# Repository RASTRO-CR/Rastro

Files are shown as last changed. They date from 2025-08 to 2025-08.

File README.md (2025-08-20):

# RASTRO: Sistema de Monitoreo Deportivo en Tiempo Real 🛰️

**RASTRO** es un sistema ciberfísico de alto rendimiento diseñado para el seguimiento en vivo de atletas en competencias deportivas como ciclismo, maratones y rallies. Utilizando una combinación de hardware IoT personalizado, comunicación LoRa de largo alcance y análisis predictivo con Modelos de Lenguaje Grandes (LLM), el sistema ofrece una solución robusta y de bajo costo para la gestión y seguridad de eventos.

```mermaid
graph TD
    subgraph Modulo_Corredor_Wearable
        A[GPS] --> C{ESP32-S3}
        B[IMU] --> C
    end

    subgraph Modulo_CC_Gateway
        E[ESP32 Dev Kit] --> F{API Backend}
    end

    subgraph Infraestructura_Central
        F -- HTTP POST --> G[Base de Datos SQLite]
        F -- Llama a API --> H[LLM en la Nube]
        H -- Respuesta --> F
        I[Frontend React] <--> F
    end

    C -- Paquete Binario LoRa --> E

    style A fill:#bbf7d0,stroke:#22c55e
    style B fill:#bbf7d0,stroke:#22c55e
    style H fill:#c4b5fd,stroke:#8b5cf6
    style I fill:#a5f3fc,stroke:#06b6d4
```

## 🎯 Objetivo del Sistema

El objetivo principal de RASTRO es democratizar el acceso a tecnología de seguimiento profesional, permitiendo a organizadores de eventos locales mejorar drásticamente la seguridad de los competidores y la experiencia de los espectadores. El sistema detecta caídas, predice tiempos de llegada y visualiza toda la acción en un dashboard web moderno e interactivo.

## ✨ Características Principales

* **Seguimiento GPS en Tiempo Real:** Visualización de la posición de cada corredor en un mapa interactivo.
* **Comunicación LoRa de Largo Alcance:** Cobertura fiable en terrenos donde la señal celular es inexistente.
* **Detección de Accidentes en el Borde:** El módulo del corredor utiliza un IMU para detectar impactos y enviar alertas de alta prioridad de forma autónoma.
* **Análisis Predictivo con IA:** Integración con un LLM para generar comentarios de carrera, predicciones y análisis de rendimiento en tiempo real.
* **Interfaz Moderna:** Un dashboard web responsivo construido con React y TypeScript para el monitoreo y la gestión de la carrera.
* **Autonomía Energética:** Módulos de hardware diseñados para operar durante horas con baterías LiPo.

## 🛠️ Stack Tecnológico

| Capa | Tecnología | Propósito |
| :--- | :--- | :--- |
| **Módulo Corredor** | ESP32-S3 (LILYGO T-Beam Supreme) | Microcontrolador principal |
| | C++ (Framework Arduino) | Lenguaje del Firmware |
| | TinyGPS++, RadioLib, XPowersLib, U8g2 | Librerías para GPS, LoRa, PMU y Pantalla |
| **Módulo CC** | ESP32 (Dev Kit) + Módulo LoRa | Gateway de Radio y Wi-Fi |
| | C++ (Framework Arduino) | Lenguaje del Firmware |
| | RadioLib, ArduinoJson | Librerías para LoRa y manejo de JSON |
| **Backend** | Python 3.11+ | Lenguaje del Servidor |
| | FastAPI, Uvicorn | Framework para la API RESTful |
| | SQLite | Base de datos ligera |
| **Frontend** | React + TypeScript + Vite | Framework de la Interfaz de Usuario |
| | Leaflet, React-Leaflet | Librería para el Mapa Interactivo |
| | TailwindCSS | Estilizado de la Interfaz |
| | Axios | Cliente HTTP para consumir la API |

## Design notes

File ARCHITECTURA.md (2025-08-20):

# Arquitectura del Sistema RASTRO

## Vista General

RASTRO está diseñado como un sistema distribuido de tres capas principales: los **Módulos Corredor** (nodos en el borde), el **Módulo de Centro de Control (CC)** (el gateway), y la **Interfaz de Usuario** (el dashboard web). La comunicación se realiza de forma inalámbrica a través de LoRa y se procesa en un backend central que se comunica con un LLM en la nube.

### Diagrama de Flujo de Datos

```mermaid
graph TD
    subgraph Modulo_Corredor_Wearable
        A[GPS] --> C{ESP32-S3}
        B[IMU] --> C
    end

    subgraph Modulo_CC_Gateway
        E[ESP32 Dev Kit] --> F{API Backend}
    end

    subgraph Infraestructura_Central
        F -- HTTP POST --> G[Base de Datos SQLite]
        F -- Llama a API --> H[LLM en la Nube]
        H -- Respuesta --> F
        I[Frontend React] <--> F
    end

    C -- Paquete Binario LoRa --> E

    style A fill:#bbf7d0,stroke:#22c55e
    style B fill:#bbf7d0,stroke:#22c55e
    style H fill:#c4b5fd,stroke:#8b5cf6
    style I fill:#a5f3fc,stroke:#06b6d4
```

## Capas del Sistema

### 1. Capa de Percepción (Sensores)
* **GPS (L76K):** Ubicado en el Módulo Corredor, captura coordenadas (latitud, longitud), velocidad, altitud y número de satélites.
* **IMU (QMI8658):** Integrado en el Módulo Corredor, mide la aceleración en 3 ejes para la detección de caídas y el análisis de movimiento.

### 2. Capa de Procesamiento Local (Firmware)
* **Módulo Corredor (C++):** Su firmware está optimizado para la eficiencia energética. Lee los sensores, empaqueta los datos en una `struct` binaria de 28 bytes y los transmite vía LoRa.
* **Módulo CC (C++):** Actúa como un puente de protocolos. Recibe el paquete de bytes de LoRa, lo decodifica, lo reconstruye como un objeto JSON y lo envía a través de Wi-Fi a la API del backend.

### 3. Capa de Comunicación
* **LoRa:** Se utiliza para la comunicación entre el corredor y el CC. Se eligió por su largo alcance y bajo consumo, ideal para exteriores.
    * **Decisión de Diseño:** Se transmiten los datos en formato binario (`struct`) en lugar de texto (JSON) para minimizar el tiempo en el aire, lo que reduce el consumo de batería y la probabilidad de colisiones de paquetes.
* **Wi-Fi / HTTP:** El Módulo CC utiliza Wi-Fi para enviar los datos ya procesados en formato JSON a un endpoint RESTful del backend.

### 4. Capa de Lógica y Visualización
* **Backend (Python/FastAPI):** Recibe los datos, los almacena en una base de datos SQLite y expone varios endpoints para que el frontend los consuma. Orquesta las llamadas al LLM para obtener análisis predictivos.
* **Frontend (React/TypeScript):** Es una Single Page Application (SPA) que consume los datos del backend. Utiliza `axios` para hacer polling a los endpoints y `react-leaflet` para visualizar las posiciones y rutas en un mapa interactivo.

## Posibles Mejoras Futuras
* **A-GPS:** Implementar un sistema de GPS Asistido donde los módulos descarguen datos de efemérides de los satélites vía Wi-Fi antes de la carrera para un posicionamiento inicial casi instantáneo.
* **Fusión de Sensores:** Implementar un Filtro de Kalman en el backend que combine los datos del GPS y del IMU para suavizar la trayectoria del corredor y estimar la posición si la señal GPS se pierde temporalmente.
* **WebSockets:** Reemplazar el polling HTTP con una comunicación por WebSockets para una actualización de datos más eficiente y en tiempo real.

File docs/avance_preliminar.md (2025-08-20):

# Avance Preliminar del Proyecto

## 1. Información del Proyecto
- **Nombre del Proyecto:** RASTRO  
- **Equipo y Roles:** 
  - Fabian: Hardware/Firmware, Frontend  
  - Sauddiel: Hardware/Firmware, Backend  

## 2. Descripción y Justificación
- **Problema que se aborda:**  
  Falta de sistemas asequibles para seguimiento en tiempo real en competencias deportivas locales, con capacidad de detectar accidentes y generar estadísticas predictivas.  
- **Importancia y contexto:**  
  Soluciona limitaciones de cobertura en zonas remotas (sin redes móviles) y reduce costos vs. sistemas profesionales. Combina IoT, LoRa y LLM para seguridad y análisis en vivo.  
- **Usuarios/beneficiarios:**  
  Atletas (seguimiento), organizadores (gestión de eventos), equipos médicos (alertas tempranas).  

## 3. Objetivos del Proyecto
- **Objetivo General:**  
  Desarrollar un sistema de seguimiento deportivo con comunicación LoRa, detección de accidentes, y predicción de métricas usando LLM.  
- **Objetivos Específicos:**  
  1. Transmitir ubicación/velocidad de corredores en tiempo real con módulos ESP32 + GPS + IMU.  
  2. Implementar algoritmo de detección de accidentes usando datos de los sensores.  
  3. Predecir tiempos de llegada y riesgos mediante LLM.  
  4. Visualizar datos en dashboard con React y mapas interactivos.  

## 4. Requisitos Iniciales
- **Lista breve de lo que el sistema debe lograr:**  
  - Capturar en tiempo real la ubicación (latitud y longitud) de cada competidor mediante GPS integrado en los módulos ESP32.  
  - Capturar los datos del componente IMU de cada competidor.
  - Transmitir los datos recopilados (posición, velocidad, aceleración, batería, etc.) a través de LoRa hacia un centro de control.
  - Recibir, decodificar y procesar los paquetes LoRa en el centro de control (ESP32 Gateway / Ideaboard), y reenviarlos como JSON al backend vía WiFi.
  - Crear la conexión con el proveedor de LLM mediante API, y realizar las consultas necesarias.
  - Implementar lógica de detección de eventos relevantes como caídas, frenazos o pérdida de señal GPS.
  - Permitir la visualización en tiempo real del estado y posición de los ciclistas a través de una interfaz web.
  - Garantizar un consumo energético eficiente durante toda la competencia.  

## 5. Diseño Preliminar del Sistema
- **Arquitectura inicial (diagrama):**  
  ```mermaid
   graph LR
    A[Módulo Corredor<br>ESP32 + GPS + LoRa] -->|LoRa - RadioLib| B[Centro de Control<br>IdeaBoard + LoRa]
    B --> |Http Request| C[Backend<br>Python + BD]
    C --> |API| D[LLM]
    C --> |FastAPi| E[Frontend<br>React + Mapas]
  ```
  
- **Componentes previstos:**  
  - Microcontrolador:  
    - Módulo Corredor: LILYGO T-Beam SUPREME (ESP32-S3).  
    - Módulo Centro de Control: IdeaBoard/ESP32 + Waveshare Módulo Core1262 HF LoRa.  
  - Sensores/actuadores:  
    - L76K GPS, LORA SX1262, IMU, antena LoRa 915Mhz.  
  - LLM/API: Together AI (LLama) para predicciones y análisis.  
  - Librerías y herramientas (C/C++):  
    - RadioLib
    - ArduinoJson
    - SPI
    - Wire
    - U8g2lib
    - XPowersLib

## 6. Plan de Trabajo
- **Cronograma preliminar:**  
  | Semana | Hitos |  
  |--------|-------|  
  | 18-25 jul | Definir stack técnico, conectar módulos LoRa. |  
  | 26 jul-1 ago | Lógica de alertas, primeros prompts LLM, GUI básica. |  
  | 2-8 ago | Implementar frontend, ajustar backend. |  
  | 9-15 ago | Pruebas integradas, entrega final (19 ago). |  

- **Riesgos identificados y mitigaciones:**  
  - **Riesgo 1:** Bateria insuficiente para cubrir toda la competencia.

    *Mitigación:* Optimizacion mediante el componente PMU.
  - **Riesgo 2:** Falsos positivos en detección de accidentes.  
    
    *Mitigación:* Calibrar/Mejorar prompts con estructura óptima.  

## 7. Prototipos conceptuales
- **Código mínimo de prueba:**  
  ```python
  from together import Together

    # Crea el cliente con tu API Key directamente
    client = Together(api_key="TuApiKeyAquí")  #Aquí iría la llave de API real

    # Puedes cambiar de modelo según necesidads
    MODEL = "meta-llama/Meta-Llama-3.1-8B-Instruct-Turbo"

    def consultar_llm(prompt):
        try:
            response = client.chat.completions.create(
                model=MODEL,
                messages=[
                    {"role": "system", "content": "Eres un experto en análisis de datos de ciclismo competitivo en tiempo real."},
                    {"role": "user", "content": prompt}
                ]
            )
            return response.choices[0].message.content
        except Exception as e:
            return f"Error en LLM: {e}"

    # Datos simulados
    datos_c1 = [
        {"timestamp": "2024-01-01T10:00:00", "lat": 9.93, "lng": -84.08, "speed": 32.1, "accel_x": 0.05, "accel_y": -0.01, "accel_z": 9.81},
        {"timestamp": "2024-01-01T10:00:10", "lat": 9.931, "lng": -84.081, "speed": 33.2, "accel_x": 0.04, "accel_y": -0.02, "accel_z": 9.80},
        {"timestamp": "2024-01-01T10:00:20", "lat": 9.932, "lng": -84.082, "speed": 31.8, "accel_x": 0.06, "accel_y": -0.01, "accel_z": 9.82}
    ]
    datos_c2 = [
        {"timestamp": "2024-01-01T10:00:00", "lat": 9.93, "lng": -84.08, "speed": 30.1, "accel_x": 0.03, "accel_y": -0.01, "accel_z": 9.75},
        {"timestamp": "2024-01-01T10:00:10", "lat": 9.931, "lng": -84.081, "speed": 29.8, "accel_x": 0.02, "accel_y": -0.01, "accel_z": 9.78},
        {"timestamp": "2024-01-01T10:00:20", "lat": 9.932, "lng": -84.082, "speed": 28.5, "accel_x": 0.01, "accel_y": -0.01, "accel_z": 9.74}
    ]

    # Esquemas
    esquemas = {
        "prediccion": {
            "ciclista_id": str,
            "estado_actual": str,
            "tendencia": str,
            "riesgos_detectados": list,
            "tiempo_estimado_llegada": str,
            "comentario_tecnico": str
        }

        # Aquí van los otros esquemas
    }

    def format_datos_tabla(datos_list):
        tabla = "timestamp,lat,lng,spd,accel_x,accel_y,accel_z\\n"
        for row in datos_list:
            tabla += f"{row['timestamp']},{row['lat']},{row['lng']},{row['speed']},{row['accel_x']},{row['accel_y']},{row['accel_z']}\\n"
        return tabla

    def build_prediccion_prompt(ciclista_id, datos_list):
        datos = format_datos_tabla(datos_list)
        return f"""
    Sos un asistente experto en análisis deportivo en tiempo real para competencias de ciclismo.

    A continuación, se presentan los datos recopilados recientemente del ciclista con ID '{ciclista_id}' en formato CSV:

    {datos}

    📌 Descripción de las columnas:
    - timestamp: marca de tiempo
    - lat, lng: coordenadas GPS
    - speed: velocidad en m/s
    - accel_x, accel_y, accel_z: aceleraciones registradas por el sensor IMU

    📋 Tu tarea:
    1. Analizar los patrones de movimiento del ciclista.
    2. Detectar si hay tendencia a mejorar o decaer.
    3. Estimar el tiempo restante de llegada con base en el ritmo.
    4. Identificar señales de cansancio, fatiga o riesgos.

    ⚠ Instrucciones estrictas:
    - Devuelve ÚNICAMENTE el siguiente JSON. No escribas nada más.
    - No incluyas encabezados, explicaciones ni bloques de código.
    - Empieza la respuesta directamente con una llave de apertura.
    - Asegurate de que sea un JSON válido.

    🔁 Devuelve la salida en el siguiente formato JSON:

    {{
    "ciclista_id": "{ciclista_id}",
    "estado_actual": "descripción breve",
    "tendencia": "ascendente | descendente | estable",
    "riesgos_detectados": ["problema1", "problema2"],
    "tiempo_estimado_llegada": "hh:mm:ss",
    "comentario_tecnico": "análisis profesional en pocas frases"
    }}
    """

    # Función genérica para probar cada prompt
    def probar_prompt(nombre, prompt, esquema):
        print(f"\n--- 🔍 Probando {nombre.upper()} ---")
        print(prompt)
        print("\n🧠 Enviando prompt...")
        respuesta = consultar_llm(prompt)
        print("\n📩 Respuesta cruda del LLM:")
        print(respuesta)

    # Ejecutar pruebas
    probar_prompt("prediccion", build_prediccion_prompt("ciclista_001", datos_c1), esquemas["prediccion"])
  ```

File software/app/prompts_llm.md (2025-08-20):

## Prompt 1: Análisis en Carrera (staff técnico)
Uso: Durante la competencia en intervalos de X km/min.

Actúa como analista técnico de ciclismo competitivo. Analiza los siguientes datos secuenciales de un ciclista para detectar tendencias, riesgos y generar predicciones:

Datos:
KM 1:
1) Velocidad: 35.2 km/h, FC: 152 bpm, Cadencia: 88 rpm
...
KM 3:
5) Velocidad: 33.0 km/h, FC: 167 bpm, Cadencia: 78 rpm

Instrucciones:
1) Indica tendencias en velocidad, FC y cadencia.
2) Señala posibles riesgos de fatiga o sobreesfuerzo.
3) Predice rendimiento para los próximos 5 km.
4) Da recomendaciones técnicas para el equipo de apoyo.

Responde de forma técnica, clara y concisa, en máximo 5 puntos.

## Prompt 2: Refinamiento a formato para Dashboard
Uso: Segunda capa si deseas refinar el resultado anterior.

Toma el siguiente análisis técnico y conviértelo en una lista de máximo 5 puntos, cada punto de máximo 2 líneas, claros y accionables para mostrar en un dashboard técnico de ciclismo.

[Pegue aquí el análisis generado por el primer prompt]

## Prompt 3: Resumen post-competencia (staff y reporte técnico)
Actúa como analista de ciclismo competitivo. Genera un resumen técnico del rendimiento del ciclista con estos datos:

- Velocidad promedio: 34.1 km/h
- FC promedio: 162 bpm
- Cadencia promedio: 83 rpm
- Ritmo en subida: 31.2 km/h
- Ritmo en llano: 35.5 km/h

Incluye:
1) Puntos fuertes.
2) Áreas de mejora.
3) Recomendaciones de entrenamiento específicas.

Usa markdown con secciones: ## Puntos Fuertes, ## Áreas de Mejora, ## Recomendaciones.

## Prompt 4: Comparación entre competidores
Actúa como analista técnico de ciclismo competitivo.

Compara estos dos ciclistas:

Juan:
- Velocidad: 34.5 km/h
- FC: 158 bpm
- Cadencia: 85 rpm

Ana:
- Velocidad: 33.9 km/h
- FC: 164 bpm
- Cadencia: 87 rpm

Analiza quién tiene mayor probabilidad de mantener o mejorar su rendimiento en los próximos 10 km y por qué.

Genera un análisis conciso en formato de tabla comparativa y conclusiones claras.

## Prompt 5: Generador de frases para transmisión en vivo
Genera 3 frases de máximo 2 líneas cada una para narración en vivo durante la competencia, que resuman de forma clara y atractiva el rendimiento del ciclista con estos datos:

- Velocidad promedio: 34.3 km/h
- FC: 161 bpm
- Cadencia: 83 rpm
- Último tramo con incremento de 0.5 km/h

Evita tecnicismos complejos, que sea entendible para el público general.

## Prompt 6: Conversión a JSON (opcional para dashboards)
Convierte este análisis en el siguiente formato JSON para ser interpretado automáticamente por un dashboard técnico:

{
  "tendencias": ["", "", ""],
  "riesgos": ["", ""],
  "predicciones": ["", ""],
  "recomendaciones": ["", ""]
}

[Pegue aquí el análisis generado]

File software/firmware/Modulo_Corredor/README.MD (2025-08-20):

<div align="center" markdown="1">
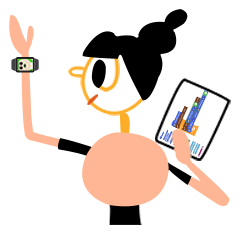
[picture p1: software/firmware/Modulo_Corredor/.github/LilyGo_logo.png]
LilyGo logo
  
</div>

<h1 align = "center">🌟LilyGo LoRa Series🌟</h1>

## News

- Arduino IDE users need to configure the board to be used in the <utilities.h> file in the sketch directory before using the example. The <utilities.h> file contains the pin definitions of the board. If you do not select it, an error will occur during compilation.
- Arduino IDE 用户需要在 Sketch 目录下的 <utilities.h> 文件的最上方配置要使用的开发板，然后才能使用该示例。<utilities.h> 文件包含开发板的引脚定义。如果您未选择该文件，编译时将出现错误。

### `1` Get Started

- 🔧 **[T-Beam Quick Start](./docs/en/t_beam/t_beam_hw.md)**
- 🔧 **[T-Beam Supreme Quick Start](./docs/en/t_beam_supreme/t_beam_supreme_hw.md)**
- 🔧 **[T-Beam BPF Quick Start](./docs/en/t_beam_bpf/t_beam_bpf_hw.md)**
- 🔧 **[T-Beam 2W Quick Start](./docs/en/t_beam_2w/t_beam_2w_hw.md)**
- 🔧 **[LoRa32 V1.3 Quick Start](./docs/en/t3_v13_sx1276/t3_v13_sx1276.md)**
- 🔧 **[LoRa32 V1.6.1 Quick Start](./docs/en/t3_v161_sx1276/t3_v161_sx1276_hw.md)**
- 🔧 **[LoRa32 TCXO Quick Start](./docs/en/t3_tcxo_sx1276/t3_tcxo_sx1276_hw.md)**
- 🔧 **[T3-C6 Quick Start](./docs/en/t3_c6_sx1262/t3_c6_sx1262_hw.md)**
- 🔧 **[T3-S3-SX1262 Quick Start](./docs/en/t3_s3_sx1262/t3_s3_sx1262_hw.md)**
- 🔧 **[T3-S3-LR1121 Quick Start](./docs/en/t3_s3_lr1121/t3_s3_lr1121_hw.md)**
- 🔧 **[T3-S3-SX1280 Quick Start](./docs/en/t3_s3_sx1280/t3_s3_sx1280_hw.md)**
- 🔧 **[T3-S3-SX1280PA Quick Start](./docs/en/t3_s3_sx1280pa/t3_s3_sx1280pa.md)**

## `2` Example description

```bash
./examples/
├── ArduinoLoRa                              # Only support SX1276/SX1278 radio module (仅支持 SX1276/SX1278 无线电模块)
│   ├── LoRaReceiver
│   └── LoRaSender
├── Display                                  # Only supports TBeam TFT Shield
│   ├── Free_Font_Demo
│   ├── TBeam_TFT_Shield
│   ├── TFT_Char_times
│   └── UTFT_demo
├── GPS                                      # T-Beam GPS demo examples
│   ├── TinyGPS_Example
│   ├── TinyGPS_FullExample
│   ├── TinyGPS_KitchenSink
│   ├── UBlox_BasicNMEARead                  # Only support Ublox GNSS Module           
│   ├── UBlox_NMEAParsing                    # Only support Ublox GNSS Module           
│   ├── UBlox_OutputRate                     # Only support Ublox GNSS Module      
│   └── UBlox_Recovery                       # Only support Ublox GNSS Module      
├── LoRaWAN                                  # LoRaWAN examples
│   ├── LMIC_Library_OTTA
│   └── RadioLib_OTAA
├── OLED
│   ├── SH1106FontUsage
│   ├── SH1106GraphicsTest
│   ├── SH1106IconMenu
│   ├── SH1106PrintUTF8
│   ├── SSD1306SimpleDemo
│   └── SSD1306UiDemo
├── PMU                                      # T-Beam & T-Beam S3 PMU demo examples
├── RadioLibExamples                         # RadioLib examples,Support SX1276/78/62/80...
│   ├── Receive_Interrupt
│   └── Transmit_Interrupt
├── Sensor                                   # Sensor examples,only support t-beams3-supreme
│   ├── BME280_AdvancedsettingsExample
│   ├── BME280_TestExample
│   ├── BME280_UnifiedExample
│   ├── PCF8563_AlarmByUnits
│   ├── PCF8563_SimpleTime
│   ├── PCF8563_TimeLib
│   ├── PCF8563_TimeSynchronization
│   ├── QMC6310_CalibrateExample
│   ├── QMC6310_CompassExample
│   ├── QMC6310_GetDataExample
│   ├── QMC6310_GetPolarExample
│   ├── QMI8658_BlockExample
│   ├── QMI8658_GetDataExample
│   ├── QMI8658_InterruptBlockExample
│   ├── QMI8658_InterruptExample
│   ├── QMI8658_LockingMechanismExample
│   ├── QMI8658_MadgwickAHRS
│   ├── QMI8658_PedometerExample
│   ├── QMI8658_ReadFromFifoExample
│   └── QMI8658_WakeOnMotion
|── T3S3Factory                              # T3 S3 factory test examples
└── Factory                                  # T-Beam & T-Beam S3 and BPF factory test examples
```

## `3` Use reference

| Product | Youtube  link | explanation | Status |
| :---: | :---: | :---: | :----: |
| T -BEAM | [Youtube link](https://www.youtube.com/watch?v=Xf1Wf-aTSmc) | How do I drive the T-Beam display  How to use T-Beam for positioning,How to use T-Beams  for communication test | ✅ |
| LilyGo device | [Youtube link](https://www.youtube.com/watch?v=f3BybP3L7ls) | How to enter boot mode to download the firmware | ✅ |

## `4` TTN

To access TTN (The Things Network), please refer to [LilyGo_LoRa_Series_Quick_Start](./docs/zh/LilyGo_LoRa_Series_Quick_Start_On_TTN_zh.md)

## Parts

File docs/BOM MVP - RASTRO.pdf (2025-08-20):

Modelo | Cantidad | Descripcion | Proveedor | Subtotal (Dolares) | Total (Dolares) | Enlace

MODULO CORREDOR - 2x

LILYGO T-BeamSUPREME Meshtastic | 2 | 915Mhz ESP32-S3 LoRa L76K GPS WiFi Bluetooth Módulo TTGO Junta de desarrollo con 1.3 pulgadas SH1106 OLED | Lilygo - AMAZON | $66,00 | $132,00 | https://a.co/d/3sMyP3N
Pack 2 Jesspow Batería recargable 18650 | 1 | 3.7V 3300mAh con Flat-Top Li-ion | JESSPOW BATTERY - AMAZON | $11,99 | $11,99 | https://a.co/d/ecw1ivI
| | | Total Modulo Corredor | $77,99 | $143,99

MODULO CC (Centro de Control) - 1x

CRCibernetica IdeaBoard | | | CRCibernetica | $0,00 | $0,00 | https://www.crcibernetica.com/crcibernetica-ideaboard/?searchid=2434289&search_query=ideaboard
BreadBoard | | | | $0,00 | $0,00
Waveshare Módulo Core1262 HF LoRa | 1 | chip SX1262, dispositivos meshtásticos, comunicación de largo alcance, antiinterferencia, adecuado para banda de sub-GHz | waveshare - AMAZON | $15,99 | $15,99 | https://a.co/d/gXY2bIv
2 unidades de antena LoRa de 915 MHz | 1 | Para interiores 5dBi Gain Omni SMA conector macho para LoRa y Meshtastic + cable de antena IPEX | jiangyuantech - AMAZON | $9,99 | $9,99 | https://a.co/d/6PJZxn3
| | | Total Modulo CC | $25,98 | $25,98
Total BOM | $103,97 | $169,97

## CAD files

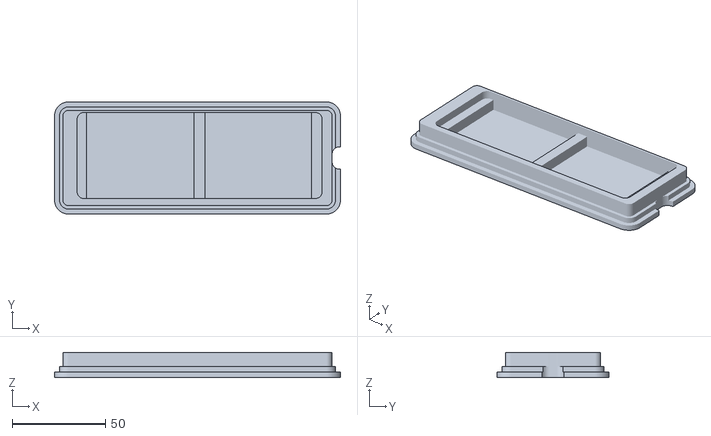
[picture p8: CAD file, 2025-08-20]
docs/Modulo_CC/TAPA ABAJO.stl
153.0 x 60.0 x 13.5

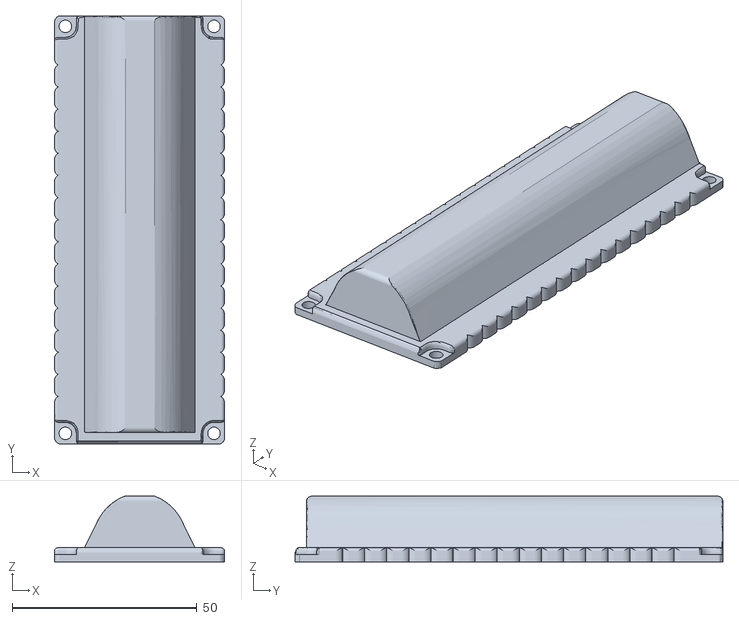
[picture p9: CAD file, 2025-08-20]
docs/Modulo_Corredor/t-beam_supreme_v14_back-18650-flat.stl
46.1 x 115.8 x 17.7

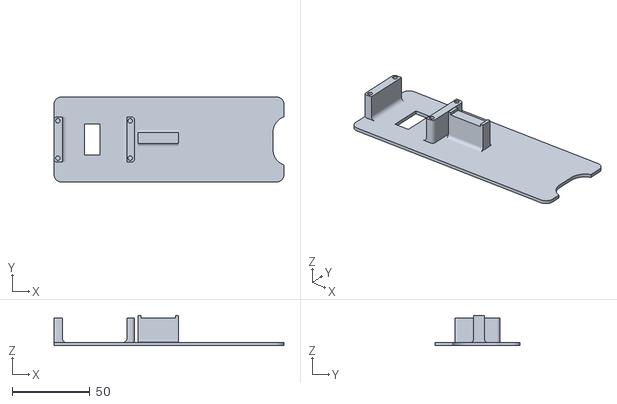
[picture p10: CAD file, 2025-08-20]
docs/Modulo_CC/INTERMEDIO.stl
147.7 x 54.7 x 19.3

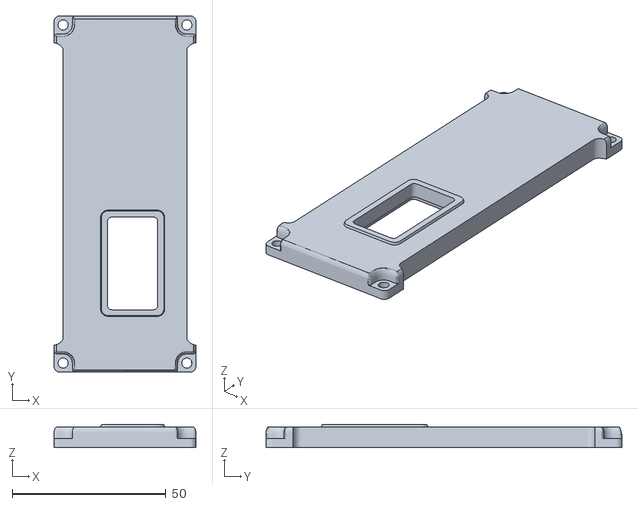
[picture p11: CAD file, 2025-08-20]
docs/Modulo_Corredor/t-beam_supreme_v14_front-blank.stl
46.2 x 115.8 x 7.49

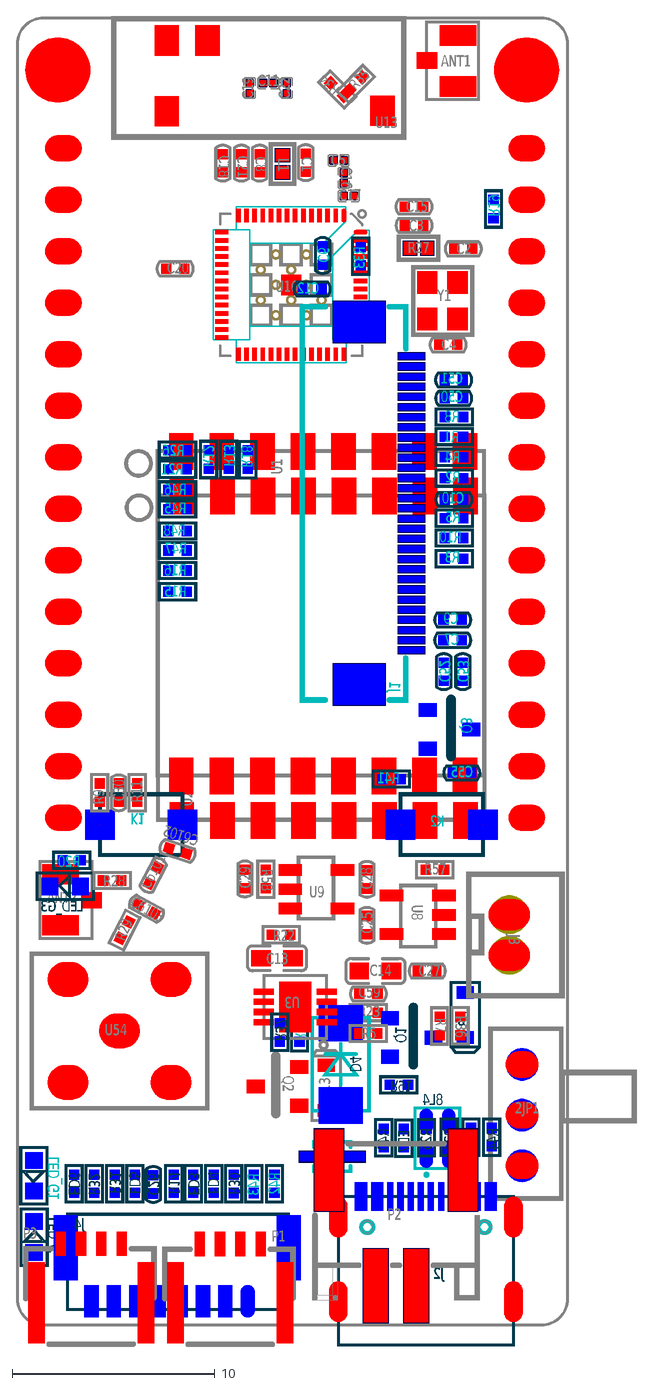
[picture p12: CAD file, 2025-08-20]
software/firmware/Modulo_Corredor/dimensions/T3S3 V1.3.dxf
U16
U54
Y1
C8
C6
R27
C20
ED4
ED6
8L4
U13
ANT1
ANT2
ED3
ED5
ED7
ED8
R19
2JP1
U8
U9
J2
C12
C15
C2
C21
C3
R33
U2
U1
LED_G
LED_G3
D13
Q3
J4
ED1
Q2
P1
P3
K1
C13
C14
C52
C10
C1
C6101
C6102
C6103
C25
C26
C27
C28
C29
C30
C50
C51
C55
R10
R11
R17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

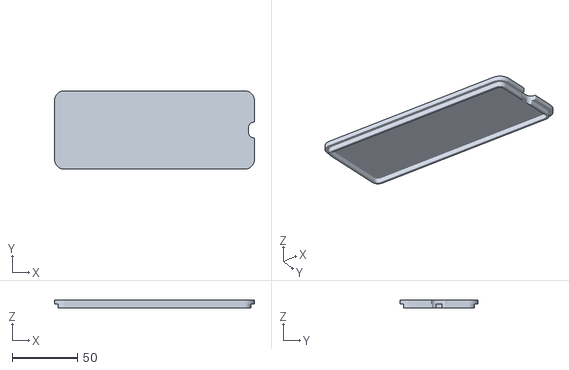
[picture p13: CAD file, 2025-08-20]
docs/Modulo_CC/TAPA ARRIBA.stl
153.0 x 60.0 x 6.00

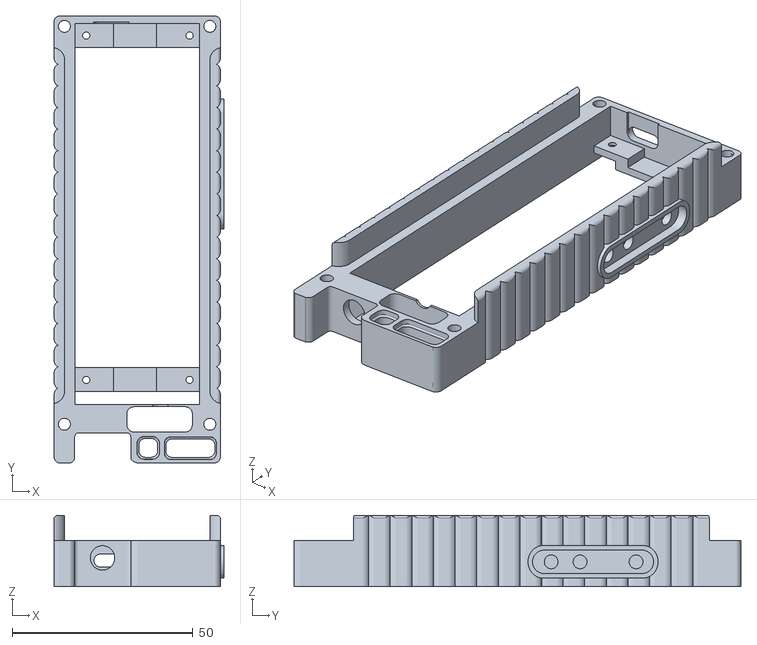
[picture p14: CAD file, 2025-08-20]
docs/Modulo_Corredor/t-beam_supreme_v14a_frame-no-button-cover.stl
47.0 x 123.7 x 19.7

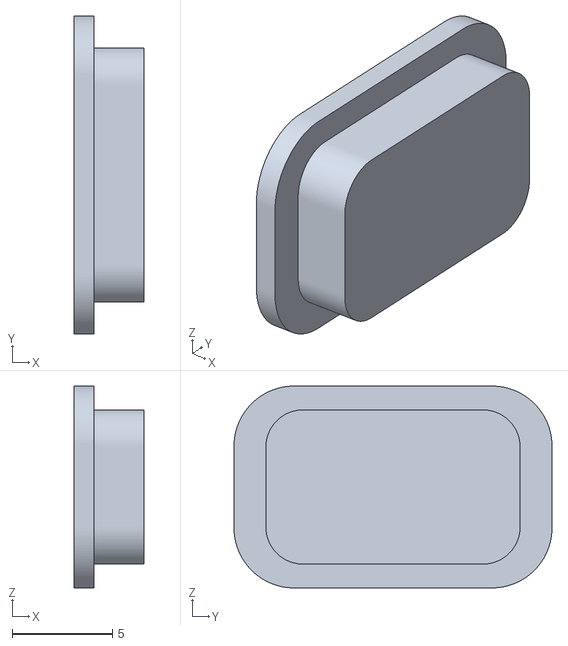
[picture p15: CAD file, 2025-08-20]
docs/Modulo_CC/TAPA POWER.stl
3.50 x 15.9 x 10.1

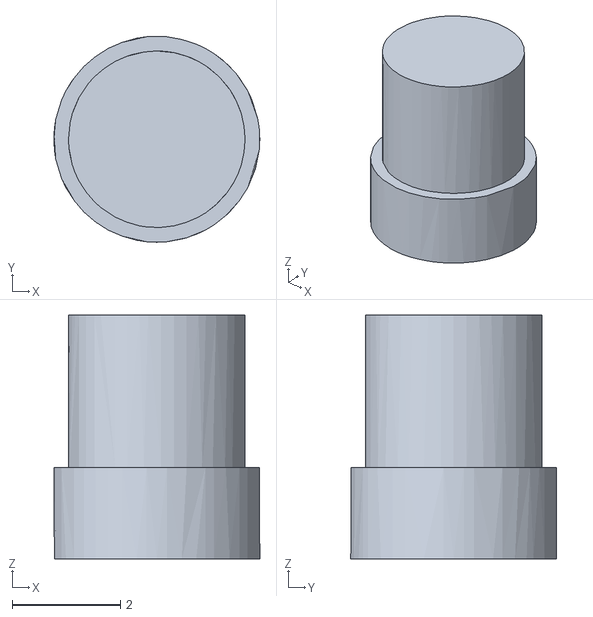
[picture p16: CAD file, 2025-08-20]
docs/Modulo_Corredor/t-beam_supreme_v14_button.stl
3.79 x 3.79 x 4.50

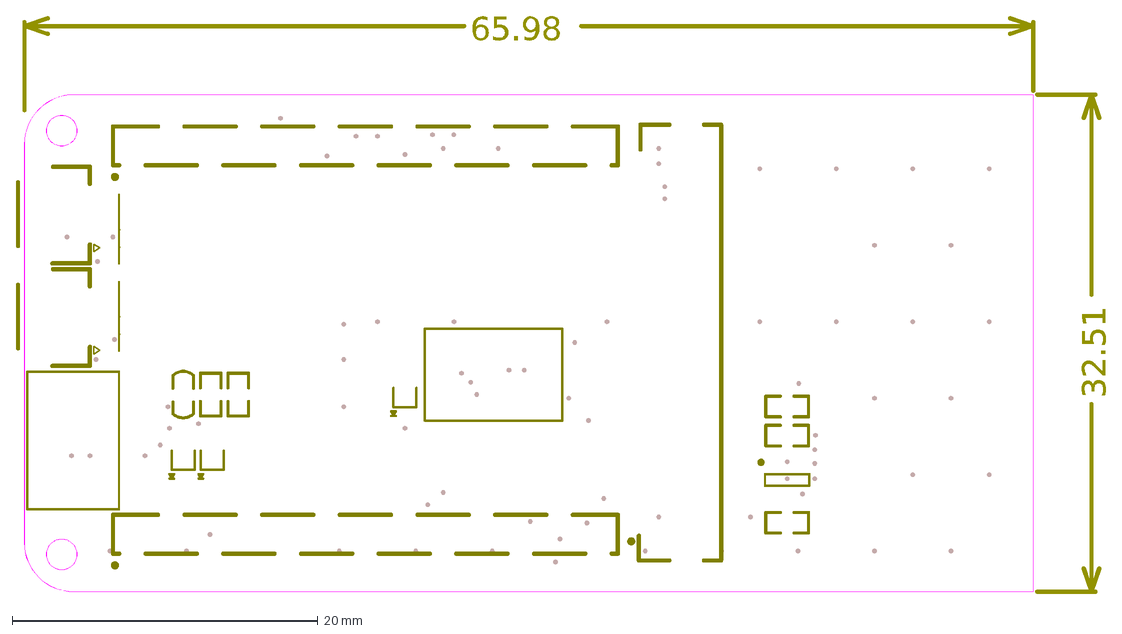
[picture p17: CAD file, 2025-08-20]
software/firmware/Modulo_Corredor/dimensions/T-Beam-Shiled-V1.0.dxf
32.51
65.98

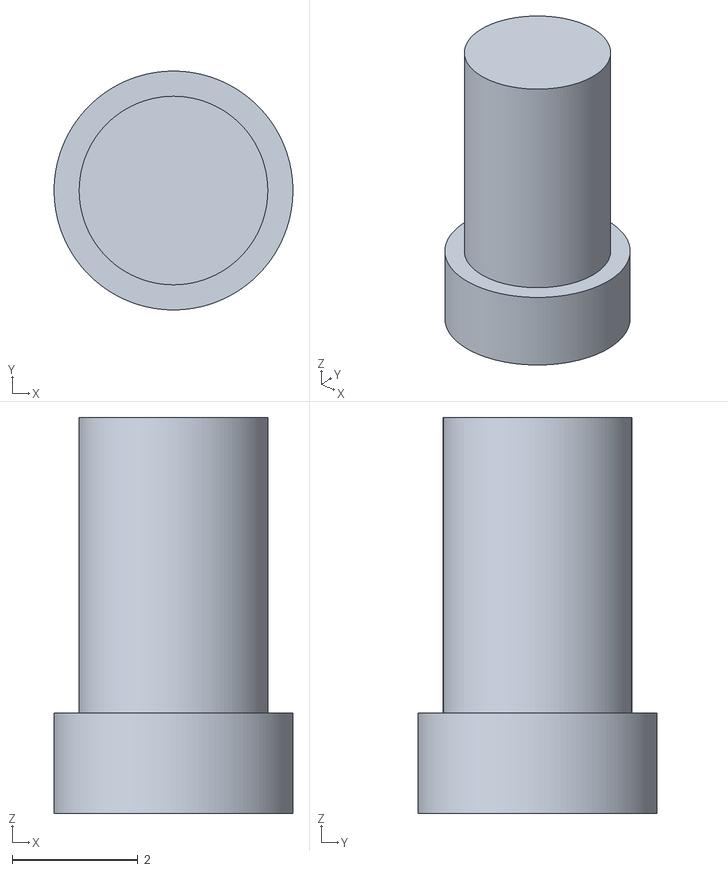
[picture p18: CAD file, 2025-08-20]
docs/Modulo_CC/BOTON.stl
3.80 x 3.80 x 6.30

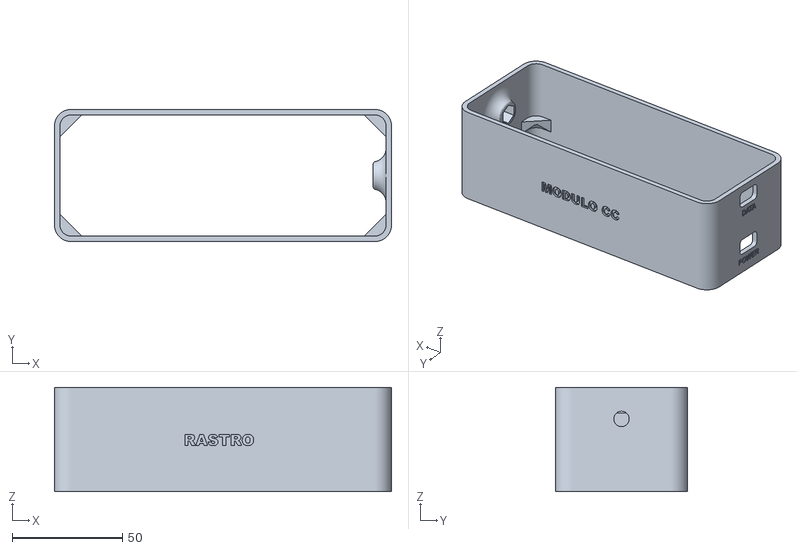
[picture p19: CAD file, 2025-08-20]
docs/Modulo_CC/CUERPO CASE.stl
153.0 x 60.0 x 47.2

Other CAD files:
software/firmware/Modulo_Corredor/dimensions/T3_V1.62.dwg
software/firmware/Modulo_Corredor/dimensions/T3_V1.3.dwg

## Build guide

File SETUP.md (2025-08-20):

# Guía de Instalación y Despliegue de RASTRO

Esta guía te permitirá configurar el entorno completo para el sistema RASTRO, desde el hardware hasta el software.

## 1. Hardware Requerido

### Módulo Corredor
* 1x Placa LILYGO T-Beam S3 Supreme
* 1x Batería LiPo 3.7V con conector JST

### Módulo de Centro de Control (CC)
* 1x Placa de desarrollo ESP32 (ej. ESP32 Dev Kit, CRCibernetica IdeaBoard)
* 1x Módulo LoRa Waveshare Core1262 (SX1262)
* 1x Antena LoRa de 915MHz con cable IPEX a SMA
* 1x Batería LiPo de 3.7V (ej. 5000mAh)
* 1x Módulo de carga LiPo TP4056
* 1x Módulo Boost Converter DC-DC MT3608
* 1x Protoboard y cables Jumper

### Diagrama de Conexiones (Módulo CC)

| Pin en ESP32 (Dev Kit) | Pin en Módulo LoRa (Waveshare) |
| :--- | :--- |
| `3V3` | `3V3` |
| `GND` | `GND` (todos los disponibles) |
| `GPIO18` | `CLK` |
| `GPIO23` | `MOSI` |
| `GPIO19` | `MISO` |
| `GPIO5` | `CS` |
| `GPIO17` | `RESET` |
| `GPIO16` | `BUSY` |
| `GPIO4` | `DIO1` |

## 2. Configuración del Firmware

1.  **Instala VS Code y la extensión PlatformIO IDE.**
2.  **Clona este repositorio:** `git clone https://github.com/your-repo`
3.  **Abre el Proyecto:** En VS Code, usa `File > Open Folder...` y abre la carpeta del repositorio clonado.
4.  **Para el Módulo Corredor:**
    * Abre el archivo `platformio.ini` en la raíz.
    * Asegúrate de que `src_dir` apunte al firmware del corredor (ej. `src_dir = software/firmware/corredor_modulo`).
    * Conecta la placa LILYGO, ponla en modo bootloader si es necesario, y haz clic en el botón "Upload" de PlatformIO.
5.  **Para el Módulo CC:**
    * Abre el archivo `platformio.ini` en la raíz.
    * Cambia `src_dir` para que apunte al firmware del CC (ej. `src_dir = software/firmware/cc_modulo`).
    * Conecta la placa ESP32 Dev Kit, ponla en modo bootloader, y haz clic en "Upload".

## 3. Configuración del Backend

1.  **Navega a la carpeta:** `cd software/backend`
2.  **Crea un entorno virtual:** `python -m venv venv`
3.  **Activa el entorno:**
    * Windows: `.\venv\Scripts\activate`
    * macOS/Linux: `source venv/bin/activate`
4.  **Instala las dependencias:** `pip install -r requirements.txt`
5.  **Ejecuta el servidor:** `python main.py`

## 4. Configuración del Frontend

1.  **Navega a la carpeta:** `cd software/frontend`
2.  **Instala las dependencias:** `npm install`
3.  **Configura la URL de la API:**
    * Crea un archivo llamado `.env` en la carpeta `frontend`.
    * Añade la siguiente línea, reemplazando la IP por la de tu PC donde corre el backend:
        `VITE_API_BASE_URL=http://192.168.100.60:8000`
4.  **Ejecuta la aplicación:** `npm run dev`
5.  Abre la URL que te proporciona la terminal en tu navegador.

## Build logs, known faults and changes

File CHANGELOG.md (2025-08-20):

# Changelog

Todo el historial de cambios notables en el proyecto RASTRO será documentado en este archivo.

El formato está basado en [Keep a Changelog](https://keepachangelog.com/en/1.0.0/), y este proyecto se adhiere a [Semantic Versioning](https://semver.org/spec/v2.0.0.html).

## [1.0.0] - 2025-08-20 (Día de la Expo)

### Added
-   **Documentación Final:** Se completaron y pulieron todos los documentos del repositorio (`README.md`, `ARCHITECTURE.md`, `SETUP.md`) para la evaluación final.
-   **Pruebas de Campo:** Se realizó una prueba de campo final del sistema completo en un entorno exterior, validando la precisión del GPS, la transmisión de datos y la visualización en el dashboard.

### Changed
-   **Versión Estable:** Se marca esta versión como la `1.0.0`, representando el prototipo funcional completo presentado en la ExpoCenfo 2025.

## [0.9.0] - 2025-08-18

### Added
-   **Integración de Actuadores en Módulo CC:** Se implementó el control de un LED RGB y un Buzzer Activo en el Módulo CC para proporcionar feedback visual y sonoro de los estados del sistema (ej. recepción de paquete, alertas).
-   **Gestión de Energía Avanzada:** Se añadió la funcionalidad de "sueño profundo" (deep sleep) al Módulo CC, controlada por un botón externo para un encendido y apagado eficiente.
-   **Diseño de Carcasas (Case):** Se diseñaron e imprimieron en 3D las carcasas finales para el Módulo Corredor y el Módulo CC, cumpliendo con el requisito de fabricación digital.

## [0.8.0] - 2025-08-15 (Entrega Final)

### Added
-   **Frontend Completo:** Se fusionaron las vistas de Administrador y Pública en una sola aplicación con navegación. Se completó el panel de configuración de carrera, incluyendo la carga de archivos GPX.
-   **Backend (Análisis LLM):** Se implementó la lógica para construir prompts dinámicos y realizar llamadas a una API de LLM externa para generar análisis de carrera.
-   **Sistema de Alertas:** Se desarrolló el motor de alertas en el backend para detectar eventos como posibles caídas basadas en los datos del IMU.

## [0.7.0] - 2025-08-12

### Added
-   **Módulo CC (Hardware Oficial):** Se ensambló y validó el Módulo CC final utilizando la placa ESP32 Dev Kit, el módulo LoRa Waveshare y el circuito de alimentación autónomo (Batería LiPo + TP4056 + MT3608).
-   **Firmware Módulo CC (Oficial):** Se adaptó y refinó el firmware del receptor para el nuevo hardware, incluyendo la decodificación de paquetes binarios y la conversión a JSON para su envío al backend.

### Fixed
-   Se resolvieron problemas de `Error -2 (CHIP_NOT_FOUND)` en el Módulo CC oficial a través de un protocolo de diagnóstico de bajo nivel (Escáner SPI) que identificó una conexión física inestable como la causa raíz.

## [0.6.0] - 2025-08-08

### Added
-   **Fusión de Sensores (GPS + IMU):** Se integró exitosamente la lectura de datos del GPS (TinyGPS++) y del IMU (QMI8658) en un único firmware para el Módulo Corredor.
-   **Transmisión de Datos Binarios:** Se definió y se implementó una `struct` de C++ para empaquetar toda la telemetría en un paquete de datos binario y eficiente de 28 bytes.
-   **Visualización Completa en Dispositivo:** La pantalla OLED del Módulo Corredor ahora muestra datos en tiempo real de los satélites GPS y el estado del sistema.

## [0.5.0] - 2025-08-03 (Entrega de Primer Avance)

### Added
-   **Backend Funcional (API):** Se desarrolló la primera versión de la API en Python con FastAPI. Incluye endpoints para recibir datos (`/datos/`) y consultar la última posición (`/datos/{ciclista_id}`).
-   **Frontend (Mapa en Vivo):** Se creó la primera versión de la interfaz de usuario con React y TypeScript, capaz de conectarse a la API y "pintar" la ubicación y el rastro de un corredor en un mapa de Leaflet.

### Fixed
-   **Precisión del GPS:** Se diagnosticó y mitigó el desfase en las coordenadas GPS mediante un protocolo de calibración en un entorno de cielo abierto.
-   **Conectividad Backend-ESP32:** Se resolvieron los errores de conexión (`Error -1`) entre el Módulo CC y el backend, diagnosticando y configurando correctamente el Firewall de Windows.

## [0.4.0] - 2025-07-28

### Added
-   **Arranque de Hardware Estable:** Se logró el arranque consistente de las placas LILYGO T-Beam S3 Supreme después de un proceso de depuración intensivo.
-   **Comunicación LoRa Estable:** Se estableció una comunicación P2P fiable entre dos módulos LILYGO.
-   **Firmware Base:** Se crearon firmwares de transmisión y recepción usando `RadioLib` para validar la capa de radio.

### Changed
-   **Pivote de Estrategia de Desarrollo:** Se adoptó el **repositorio oficial de LilyGo** como entorno de desarrollo base para garantizar la compatibilidad del hardware.

### Fixed
-   **Error Crítico de Arranque:** Se solucionó el fallo que impedía que el firmware se ejecutara en las placas LILYGO al añadir la `build_flag` `-DARDUINO_USB_CDC_ON_BOOT=1` al `platformio.ini`.

## [0.2.0] - 2025-07-24

### Added
-   **Análisis de Arquitectura:** Se diseñó la arquitectura de hardware y software del MVP, incluyendo la selección de componentes y el flujo de datos.
-   **Estructura del Repositorio:** Se creó el repositorio en GitHub con la estructura profesional recomendada (`docs`, `hardware`, `software`, etc.).
-   **Documentación Inicial:** Se crearon los borradores de `README.md` y `ARCHITECTURE.md`.

## [0.1.0] - 2025-07-20

### Added
-   **Concepción del Proyecto:** Se definió la idea, los objetivos y el alcance del proyecto RASTRO.
-   **Análisis de Requisitos:** Se estudió la rúbrica y las reglas de la ExpoCenfo 2025 para alinear el desarrollo del proyecto con los criterios de evaluación.

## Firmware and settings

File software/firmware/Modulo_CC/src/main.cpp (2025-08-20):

/**
 * @file main.cpp
 * @author Fabian Miranda & Sauddiel Montoya
 * @brief Firmware para el Módulo de Centro de Control (CC) del proyecto RASTRO.
 * @version 1.5
 * @date 2025-08-20
 * * @copyright Copyright (c) 2025
 * * Este firmware se encarga de recibir paquetes de telemetría vía LoRa desde los
 * Módulos Corredor, decodificarlos, convertirlos a formato JSON y enviarlos a un
 * backend a través de Wi-Fi para su procesamiento y visualización.
 */

// ==========================================================================
// Inclusión de Librerías
// ==========================================================================
#include <Arduino.h>
#include <RadioLib.h>
#include <WiFi.h>
#include <HTTPClient.h>
#include <ArduinoJson.h>

// ==========================================================================
// Constantes y Definiciones Globales
// ==========================================================================

// --- Credenciales y Endpoints ---
const char* ssid = "Wifi Montoya";
const char* password = "8A8960WM59";
const char* backendUrl = "http://192.168.100.60:8000/datos/";

// --- Definición de Pines de Hardware ---
// Pines para la comunicación SPI con el módulo LoRa SX1262.
#define LORA_CS_PIN   5
#define LORA_DIO1_PIN 4
#define LORA_RST_PIN  17
#define LORA_BUSY_PIN 16

// Pines para el control del indicador LED RGB.
#define RGB_R_PIN 32
#define RGB_G_PIN 33
#define RGB_B_PIN 25

// ==========================================================================
// Objetos Globales
// ==========================================================================

/**
 * @brief Objeto principal para la comunicación con el módulo de radio LoRa.
 * Se inicializa con los pines de control definidos previamente.
 * Utiliza el bus SPI por defecto del ESP32.
 */
SX1262 radio = new Module(LORA_CS_PIN, LORA_DIO1_PIN, LORA_RST_PIN, LORA_BUSY_PIN);

/**
 * @brief Estructura de datos para la telemetría.
 * Este "molde" define el formato binario de los paquetes enviados por LoRa.
 * Debe ser idéntico en el firmware del transmisor (Módulo Corredor) y
 * del receptor (Módulo CC) para asegurar una decodificación correcta.
 * El empaquetado de 1 byte (#pragma pack) asegura que no haya relleno entre
 * los miembros de la estructura, manteniendo un tamaño de paquete predecible.
 */
#pragma pack(push, 1)
struct RastroData {
    uint32_t timestamp;
    int32_t latitude;
    int32_t longitude;
    uint16_t battery;
    uint16_t speed_cmps;
    uint8_t satellites;
    uint8_t hdop_x10;
    int16_t accel_x;
    int16_t accel_y;
    int16_t accel_z;
    int16_t gyro_x;
    int16_t gyro_y;
    int16_t gyro_z;
    uint8_t racer_id;
    uint8_t flags;
};
#pragma pack(pop)

// ==========================================================================
// Funciones Auxiliares
// ==========================================================================

/**
 * @brief Controla el color del LED RGB.
 * Utiliza los canales PWM (LEDC) del ESP32 para permitir control de brillo.
 * * @param r Valor de 0 a 255 para el canal Rojo.
 * @param g Valor de 0 a 255 para el canal Verde.
 * @param b Valor de 0 a 255 para el canal Azul.
 */
void setLedColor(int r, int g, int b) {
    ledcWrite(0, r); // Canal 0 para Rojo
    ledcWrite(1, g); // Canal 1 para Verde
    ledcWrite(2, b); // Canal 2 para Azul
}

// ==========================================================================
// Función de Configuración Principal (Setup)
// ==========================================================================
void setup() {
    Serial.begin(115200);
    while (!Serial && millis() < 2000); // Esperar por el monitor serie
    Serial.println("\n--- MÓDULO CC RASTRO v1.5 ---");

    // --- Configuración del periférico LEDC para el control PWM del LED ---
    ledcSetup(0, 5000, 8); // Canal 0, frecuencia 5kHz, resolución de 8 bits
    ledcSetup(1, 5000, 8); // Canal 1
    ledcSetup(2, 5000, 8); // Canal 2
    ledcAttachPin(RGB_R_PIN, 0);
    ledcAttachPin(RGB_G_PIN, 1);
    ledcAttachPin(RGB_B_PIN, 2);

    // --- Conexión a la Red Wi-Fi ---
    setLedColor(0, 0, 255); // LED en azul para indicar "Conectando..."
    WiFi.mode(WIFI_STA);
    WiFi.begin(ssid, password);
    Serial.print("Conectando a WiFi...");
    while (WiFi.status() != WL_CONNECTED) {
        delay(500);
        Serial.print(".");
    }
    Serial.println("\nWiFi conectado!");
    Serial.print("IP: ");
    Serial.println(WiFi.localIP());

    // --- Inicialización del Módulo LoRa ---
    int state = radio.begin(915.0, 125.0, 9, 7);
    if (state != RADIOLIB_ERR_NONE) {
        Serial.printf("Fallo al iniciar LoRa, código: %d\n", state);
        setLedColor(255, 0, 0); // LED en rojo para indicar error crítico
        while (true);
    }
    
    Serial.println("¡Receptor listo! Escuchando paquetes...");
    radio.startReceive();
}

// ==========================================================================
// Bucle Principal (Loop)
// ==========================================================================
void loop() {
    // Efecto de "respiración" para el LED verde, indicando estado de espera.
    float breath = (exp(sin(millis()/2000.0*PI)) - 0.36787944)*108.0;
    setLedColor(0, (int)breath, 0);

    // Crear un objeto para almacenar los datos del paquete entrante.
    RastroData dataPacket;

    // Intentar leer un paquete de LoRa. readData es no bloqueante.
    int state = radio.readData((uint8_t*)&dataPacket, sizeof(dataPacket));

    // Si se recibe un paquete (state == RADIOLIB_ERR_NONE) Y es del corredor que nos interesa...
    if (state == RADIOLIB_ERR_NONE && dataPacket.racer_id == 1) {
        setLedColor(255, 255, 255); // Destello blanco para indicar recepción exitosa.
        Serial.printf("Paquete binario recibido de ciclista #%d\n", dataPacket.racer_id);

        // Convertir los datos binarios a unidades legibles (float).
        float lat = dataPacket.latitude / 1e7;
        float lng = dataPacket.longitude / 1e7;
        float speed = dataPacket.speed_cmps / 100.0;
        float accelX = dataPacket.accel_x / 1000.0;
        float accelY = dataPacket.accel_y / 1000.0;
        float accelZ = dataPacket.accel_z / 1000.0;
        float gyro_x = dataPacket.gyro_x / 1000.0;
        float gyro_y = dataPacket.gyro_y / 1000.0;
        float gyro_z = dataPacket.gyro_z / 1000.0;
        float battery = dataPacket.battery;

        // Crear el documento JSON para enviar al backend.
        StaticJsonDocument<256> jsonDoc;
        jsonDoc["ciclista_id"] = "ciclista" + String(dataPacket.racer_id);
        jsonDoc["lat"] = lat;
        jsonDoc["lng"] = lng;
        jsonDoc["spd"] = speed;
        jsonDoc["accel_x"] = accelX;
        jsonDoc["accel_y"] = accelY;
        jsonDoc["accel_z"] = accelZ;
        jsonDoc["gyro_x"] = gyro_x;
        jsonDoc["gyro_y"] = gyro_y;
        jsonDoc["gyro_z"] = gyro_z; 
        jsonDoc["battery"] = battery;
    
        String jsonPayload;
        serializeJson(jsonDoc, jsonPayload);
        Serial.println("Enviando JSON al backend:");
        Serial.println(jsonPayload);

        // Enviar los datos al backend vía HTTP POST si hay conexión Wi-Fi.
        if (WiFi.status() == WL_CONNECTED) {
            HTTPClient http;
            http.begin(backendUrl);
            http.addHeader("Content-Type", "application/json");
            int httpResponseCode = http.POST(jsonPayload);

            if (httpResponseCode > 0) {
                Serial.println("Solicitud enviada correctamente.");
            } else {
                Serial.printf("Error en la solicitud: %s\n", http.errorToString(httpResponseCode).c_str());
                setLedColor(255, 0, 0); // Rojo si falla el POST
                delay(1000); // Mantener el rojo por 1 segundo
            }
            http.end();
        } else {
            Serial.println("WiFi desconectado");
        }

        delay(100); // Pequeña pausa para que el destello blanco sea visible.

    } else if (state != RADIOLIB_ERR_RX_TIMEOUT) {
        // Ignorar timeouts (normal cuando no hay paquetes), pero reportar otros errores.
        Serial.printf("Fallo al recibir, código: %d\n", state);
    }

    delay(1000); // Pequeña pausa para no saturar el procesador.
}

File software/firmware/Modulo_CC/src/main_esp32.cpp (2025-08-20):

// #include <Arduino.h>
// #include <RadioLib.h>
// #include <WiFi.h>
// #include <HTTPClient.h>
// #include <ArduinoJson.h> // <-- Incluimos la librería JSON

// // --- Credenciales y Endpoints ---
// const char* ssid = "Wifi Montoya";
// const char* password = "8A8960WM59";
// const char* backendUrl = "http://192.168.100.6:8000/datos/"; // Usa tu IP correcta

// // --- PINES ESP32 ---
// // --- PASO 1: Pines corregidos para tu montaje en Protoboard ---
// #define LORA_CS_PIN   5
// #define LORA_DIO1_PIN 4
// #define LORA_RST_PIN  17
// #define LORA_BUSY_PIN 16
// // Los pines SPI (18, 19, 23) son manejados por defecto, no necesitamos definirlos.

// // --- PASO 2: Simplificación del objeto de radio ---
// // Ya no necesitamos un SPIClass personalizado. RadioLib usará el SPI por defecto.
// SX1262 radio = new Module(LORA_CS_PIN, LORA_DIO1_PIN, LORA_RST_PIN, LORA_BUSY_PIN);


// // --- Definir el "molde" de datos (DEBE SER IDÉNTICO AL DEL MÓDULO CORREDOR) ---
// struct RastroData {
//     uint32_t timestamp;   // 4 bytes
//     int32_t latitude;     // 4 bytes
//     int32_t longitude;    // 4 bytes
//     uint16_t battery_mv;  // 2 bytes
//     uint16_t speed_cmps;  // 2 bytes
//     uint8_t satellites;   // 1 byte
//     uint8_t hdop_x10;     // 1 byte
//     int16_t accel_x;      // 2 bytes
//     int16_t accel_y;      // 2 bytes
//     int16_t accel_z;      // 2 bytes
//     uint8_t racer_id;    // 1 byte
//     uint8_t flags;        // 1 byte
// };

// void setup() {
//     Serial.begin(115200);
//     while (!Serial && millis() < 2000); // Esperar por el monitor serie
//     Serial.println("\n--- MÓDULO CC RASTRO v1.0 ---");

//     // Conectar a Wi-Fi
//     WiFi.mode(WIFI_STA);
//     WiFi.begin(ssid, password);
//     Serial.print("Conectando a WiFi...");
//     while (WiFi.status() != WL_CONNECTED) {
//         delay(500);
//         Serial.print(".");
//     }
//     Serial.println("\nWiFi conectado!");
//     Serial.print("IP: ");
//     Serial.println(WiFi.localIP());

//     // Inicializar LoRa
//     // spi_lora.begin(LORA_SCK_PIN, LORA_MISO_PIN, LORA_MOSI_PIN, LORA_CS_PIN);
//     int state = radio.begin(915.0, 125.0, 9, 7);
//     if (state != RADIOLIB_ERR_NONE) {
//         Serial.printf("Fallo al iniciar LoRa, código: %d\n", state);
//         while (true);
//     }
    
//     Serial.println("¡Receptor listo! Escuchando paquetes...");
//     radio.startReceive();
// }

// void loop() {
//     // 1. Crear un "molde" vacío para recibir los datos
//     RastroData dataPacket;

//     // 2. Intentar leer los bytes entrantes y meterlos en el molde
//     int state = radio.readData((uint8_t*)&dataPacket, sizeof(dataPacket));

//     if (state == RADIOLIB_ERR_NONE) {
//         Serial.printf("Paquete binario recibido de ciclista #%d\n", dataPacket.racer_id);
//         // Serial.printf("  Lat: %.4f, Lng: %.4f, Spd: %.2f\n", dataPacket.lat, dataPacket.lng, dataPacket.spd);

//         // Convertimos a tipos legibles
//         float lat = dataPacket.latitude / 1e7;
//         float lng = dataPacket.longitude / 1e7;
//         float speed = dataPacket.speed_cmps / 100.0;
//         float hdop = dataPacket.hdop_x10 / 10.0;
//         float accelX = dataPacket.accel_x / 1000.0;
//         float accelY = dataPacket.accel_y / 1000.0;
//         float accelZ = dataPacket.accel_z / 1000.0;
//         float battery = dataPacket.battery_mv / 1000.0;
//         float gyro_x = 0;        // 4 bytes
//         float gyro_y = 0;        // 4 bytes
//         float gyro_z = 0;      // 4 bytes
//         // Serial debug opcional
//         Serial.printf("  Lat: %.6f, Lng: %.6f, Vel: %.2f m/s\n", lat, lng, speed);

//         // Crear JSON
//         StaticJsonDocument<256> jsonDoc;
//         jsonDoc["ciclista_id"] = "ciclista" + String(dataPacket.racer_id);
//         jsonDoc["lat"] = lat;
//         jsonDoc["lng"] = lng;
//         jsonDoc["spd"] = speed;
//         jsonDoc["accel_x"] = accelX;
//         jsonDoc["accel_y"] = accelY;
//         jsonDoc["accel_z"] = accelZ;
//         jsonDoc["gyro_x"] = gyro_x;
//         jsonDoc["gyro_y"] = gyro_y;
//         jsonDoc["gyro_z"] = gyro_z; 
//         // jsonDoc["battery"] = battery;
//         // jsonDoc["hdop"] = hdop;
//         // jsonDoc["satellites"] = dataPacket.satellites;
//         // jsonDoc["timestamp"] = dataPacket.timestamp;
    

//         // 3. Crear el documento JSON a partir del molde
//         // StaticJsonDocument<256> jsonDoc;
//         // // Usamos .set() para añadir los valores del struct al JSON.
//         // // ¡Las claves deben coincidir con lo que espera tu API en Python!
//         // jsonDoc["ciclista_id"] = "ciclista" + String(dataPacket.ciclista_id);
//         // jsonDoc["lat"] = dataPacket.lat;
//         // jsonDoc["lng"] = dataPacket.lng;
//         // jsonDoc["spd"] = dataPacket.spd;
//         // jsonDoc["accel_x"] = dataPacket.accel_x;
//         // jsonDoc["accel_y"] = dataPacket.accel_y;
//         // jsonDoc["accel_z"] = dataPacket.accel_z;
//         // jsonDoc["gyro_x"] = dataPacket.gyro_x;
//         // jsonDoc["gyro_y"] = dataPacket.gyro_y;
//         // jsonDoc["gyro_z"] = dataPacket.gyro_z;

//         String jsonPayload;
//         serializeJson(jsonDoc, jsonPayload); // Convertir el documento a un String

//         Serial.println("Enviando JSON al backend:");
//         Serial.println(jsonPayload);

//         // 4. Enviar el JSON al servidor
//         if (WiFi.status() == WL_CONNECTED) {
//             HTTPClient http;
//             http.begin(backendUrl);
//             http.addHeader("Content-Type", "application/json");

//             int httpResponseCode = http.POST(jsonPayload);

//             if (httpResponseCode > 0) {
//                 Serial.printf("Respuesta del backend: %d\n", httpResponseCode);
//                 String response = http.getString();
//                 Serial.println(response);
//             } else {
//                 Serial.printf("Error en la solicitud: %s\n", http.errorToString(httpResponseCode).c_str());
//             }
//             http.end();
//         } else {
//             Serial.println("WiFi desconectado");
//         }

//     } else if (state != RADIOLIB_ERR_RX_TIMEOUT) {
//         // Ignoramos los timeouts (cuando no llega nada), pero mostramos otros errores.
//         Serial.printf("Fallo al recibir, código: %d\n", state);
//     }
// }

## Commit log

2025-08-20 ExpoCenfo (#2)
    * Add initial directories
    * add backend
    * add Modulo_CC test http
    * update backend
    * feat: add modulo corredor v1
    * feat: add modulo cc v1
    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
    [T-Beam-Shiled-V1.0.dxf, T3S3 V1.3.dxf, T3_V1.3.dwg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]
2025-08-20 add docs
    [BOTON.stl, CUERPO CASE.stl, INTERMEDIO.stl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]
